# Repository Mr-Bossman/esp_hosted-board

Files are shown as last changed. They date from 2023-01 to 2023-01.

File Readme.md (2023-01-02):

# Test board for esp-hosted-ng

## Esp-hosted-ng is a SDIO/SPI WIFI/BT module for hosts runing Linux

To test ESP-Hosted-ng I designed this board to plug into and SD-card slot for easy testing.

The mothod I used before has some major signal integrity loss due to the jumper wires I used.

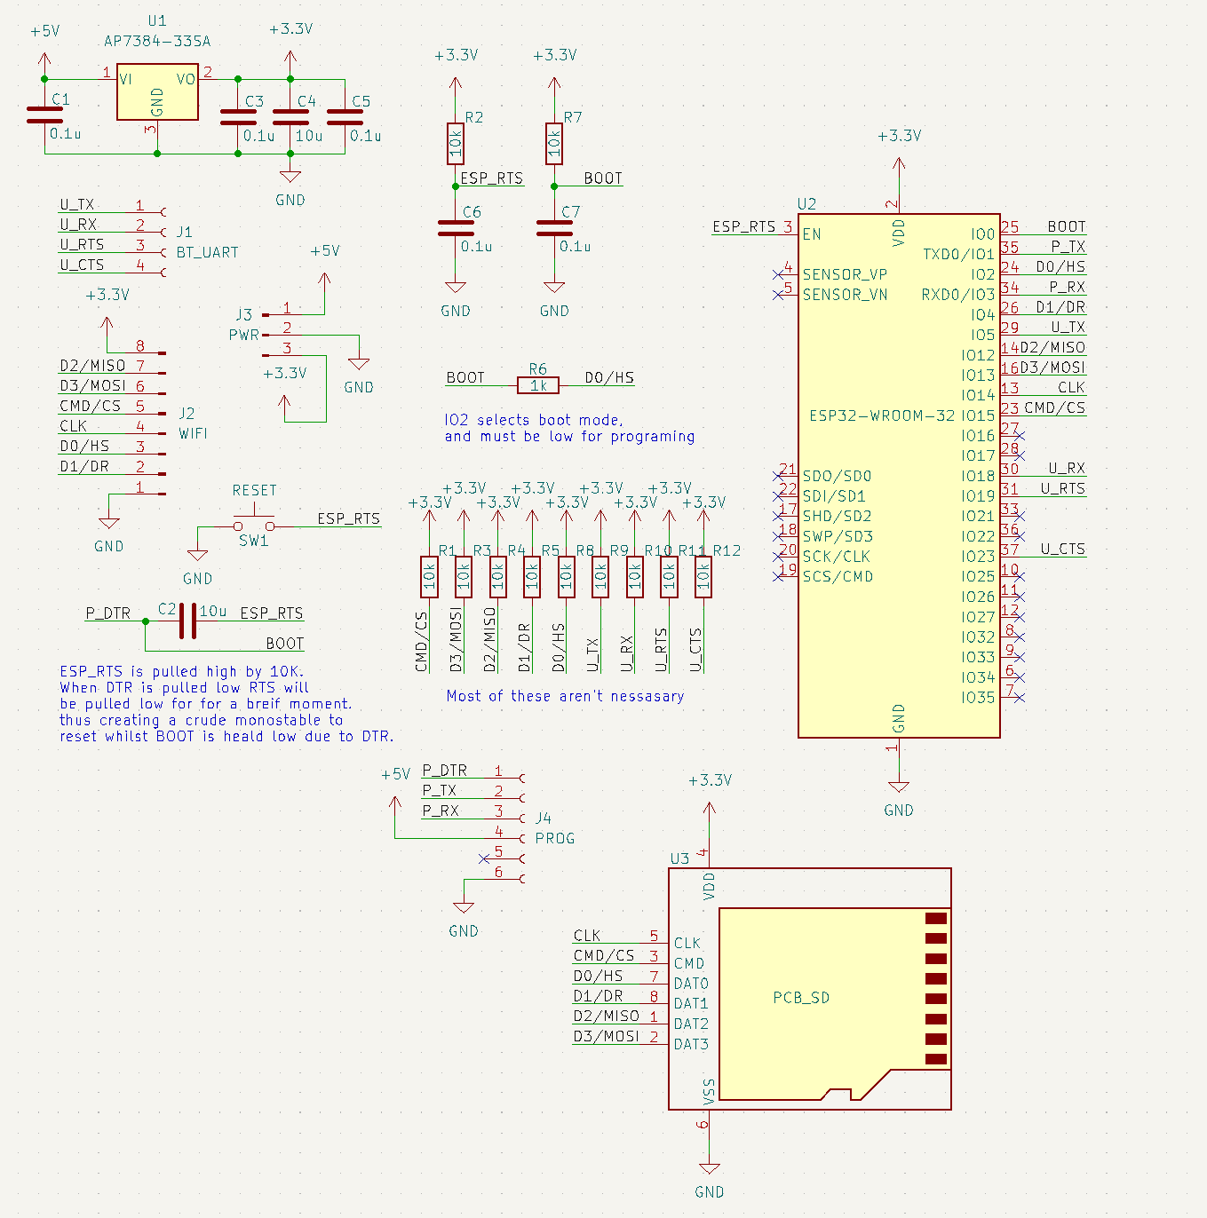
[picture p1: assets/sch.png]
Image of sch


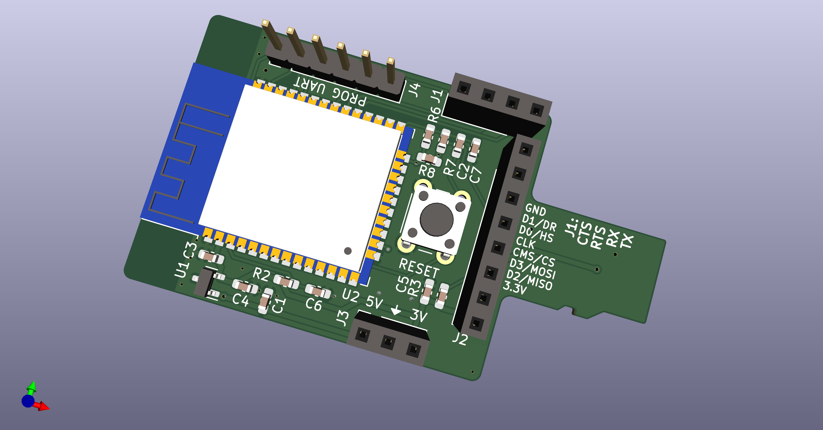
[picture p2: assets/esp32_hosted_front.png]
3D render of front


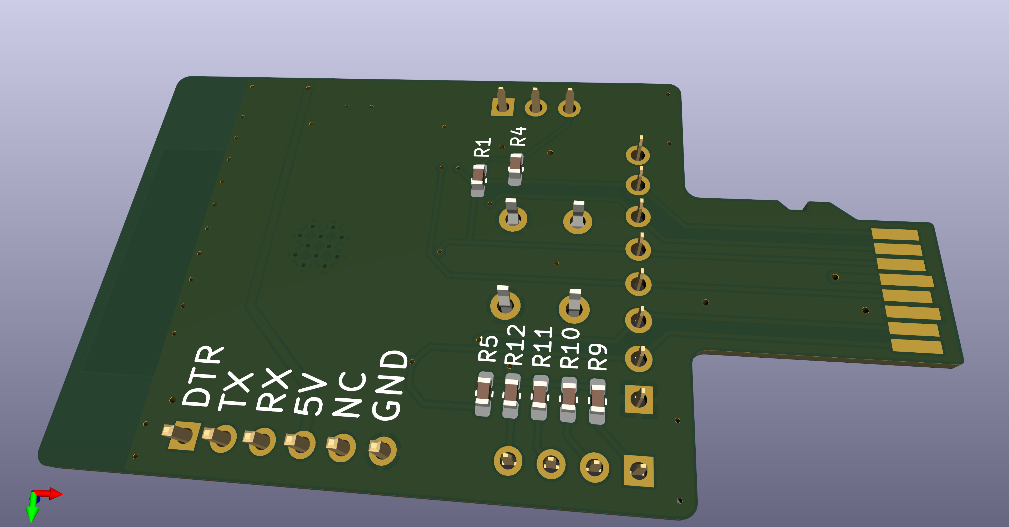
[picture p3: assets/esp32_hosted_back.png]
3D render of back


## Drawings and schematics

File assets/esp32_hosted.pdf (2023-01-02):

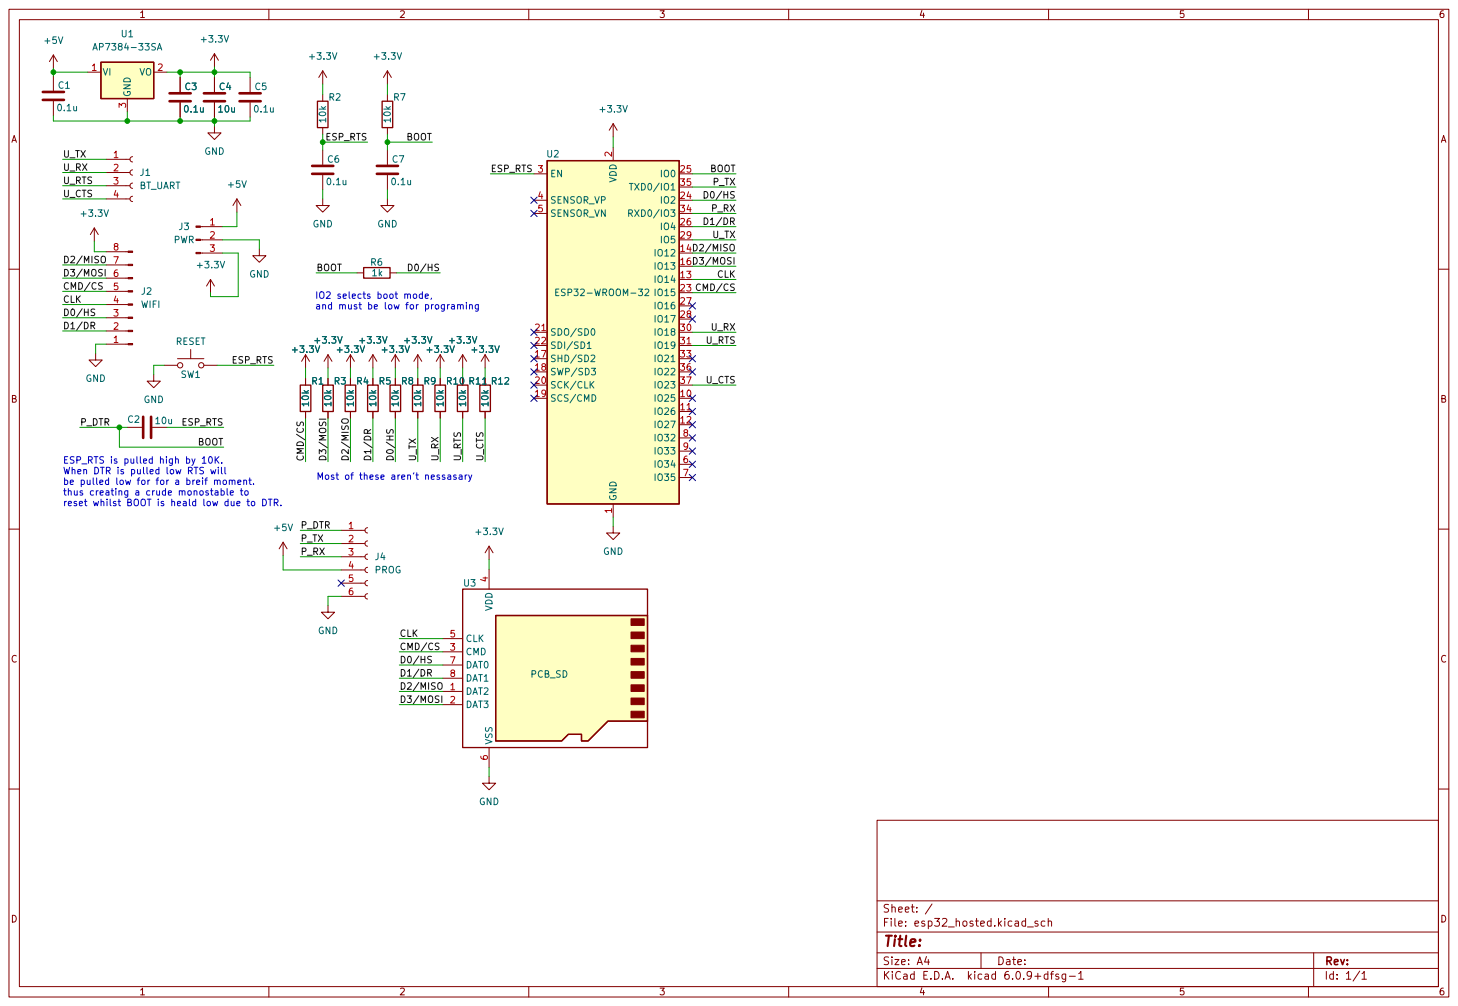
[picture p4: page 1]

reset whilst BOOT is heald low due to DTR. C3
J2WIFI GND 1234
BOOT U_CTS CLK D0/HS U_RX D2/MISO

IO2 selects boot mode, and must be low for programing

ESP_RTS is pulled high by 10K.
When DTR is pulled low RTS will
be pulled low for for a breif moment.
thus creating a crude monostable to

Most of these aren't nessasary

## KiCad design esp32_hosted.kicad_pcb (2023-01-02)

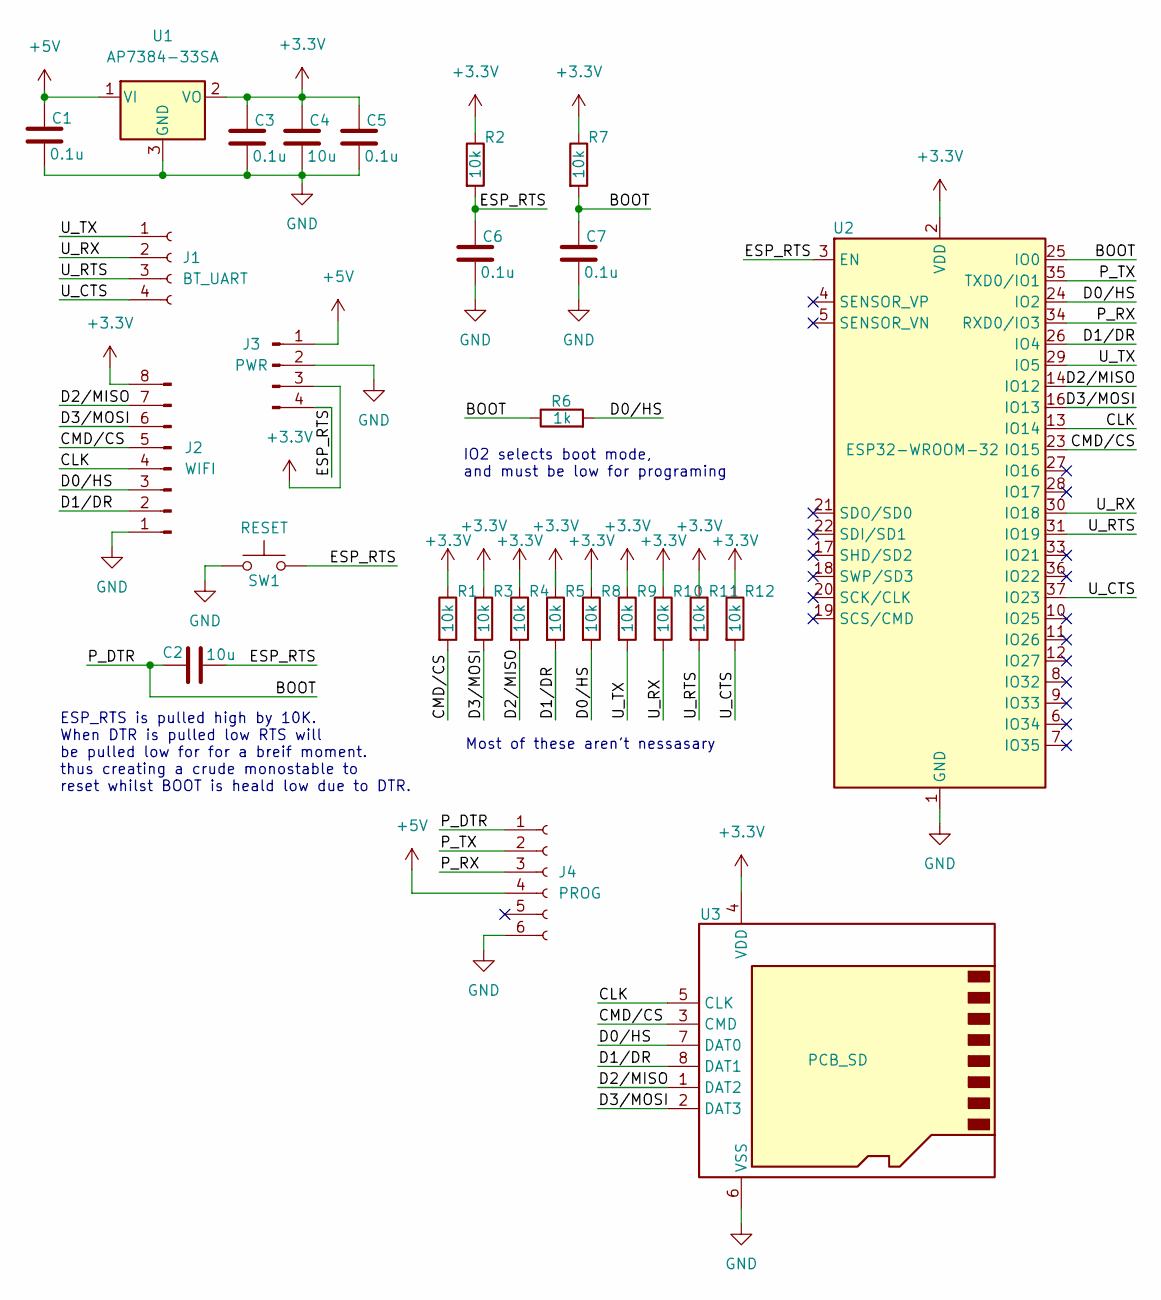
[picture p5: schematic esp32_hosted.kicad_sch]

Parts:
C1, C3, C5, C6, C7: 0.1u; C_0603_1608Metric_Pad1.08x0.95mm_HandSolder
C2, C4: 10u; C_0603_1608Metric_Pad1.08x0.95mm_HandSolder
J1: BT_UART; PinSocket_1x04_P2.54mm_Vertical
J2: WIFI; PinSocket_1x08_P2.54mm_Vertical
J3: PWR; PinSocket_1x04_P2.54mm_Vertical
J4: PROG; PinHeader_1x06_P2.54mm_Vertical
R1, R2, R3, R4, R5, R7, R8, R9, R10, R11, R12: 10k; C_0603_1608Metric_Pad1.08x0.95mm_HandSolder
R6: 1k; C_0603_1608Metric_Pad1.08x0.95mm_HandSolder
SW1: RESET; SW_PUSH_6mm
U1: AP7384-33SA; SOT-23
U2: ESP32-WROOM-32
U3: PCB_SD; PCB-SD

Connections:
+3.3V: C3.1, C4.1, C5.1, J2.8, J3.3, R1.1, R2.1, R3.1, R4.1, R5.1, R7.1, R8.1, R9.1, R10.1, R11.1, R12.1, U1.2 (VO), U2.2 (VDD), U3.4 (VDD)
+5V: C1.1, J3.1, J4.4, U1.1 (VI)
/BOOT: C2.1, C7.1, J4.1, R6.1, R7.2, U2.25 (IO0)
/CLK: J2.4, U2.13 (IO14), U3.5 (CLK)
/CMD/CS: J2.5, R1.2, U2.23 (IO15), U3.3 (CMD)
/D0/HS: J2.3, R6.2, R8.2, U2.24 (IO2), U3.7 (DAT0)
/D1/DR: J2.2, R5.2, U2.26 (IO4), U3.8 (DAT1)
/D2/MISO: J2.7, R4.2, U2.14 (IO12), U3.1 (DAT2)
/D3/MOSI: J2.6, R3.2, U2.16 (IO13), U3.2 (DAT3)
/ESP_RTS: C2.2, C6.1, J3.4, R2.2, SW1.2, U2.3 (EN)
/P_RX: J4.3, U2.34 (RXD0/IO3)
/P_TX: J4.2, U2.35 (TXD0/IO1)
/U_CTS: J1.4, R12.2, U2.37 (IO23)
/U_RTS: J1.3, R11.2, U2.31 (IO19)
/U_RX: J1.2, R10.2, U2.30 (IO18)
/U_TX: J1.1, R9.2, U2.29 (IO5)
GND: C1.2, C3.2, C4.2, C5.2, C6.2, C7.2, J2.1, J3.2, J4.6, SW1.1, U1.3 (GND), U2.1 (GND), U2.15 (GND), U2.38 (GND), U2.39 (GND), U3.6 (VSS)

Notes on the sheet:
IO2 selects boot mode, and must be low for programing
ESP_RTS is pulled high by 10K. When DTR is pulled low RTS will be pulled low for for a breif moment. thus creating a crude monostable to reset whilst BOOT is heald low due to DTR.
Most of these aren't nessasary

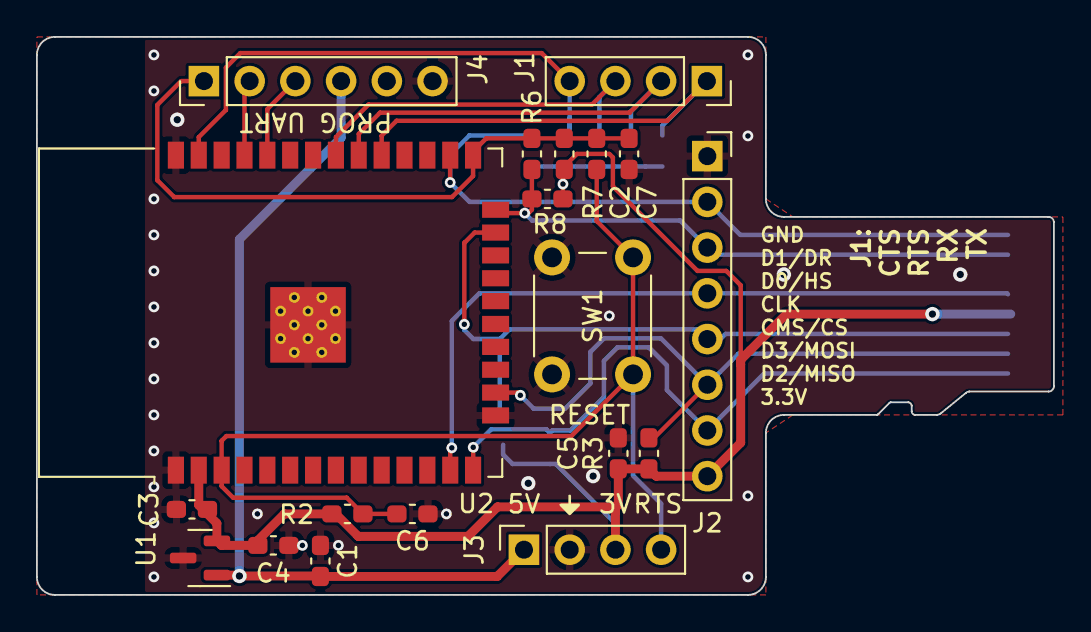
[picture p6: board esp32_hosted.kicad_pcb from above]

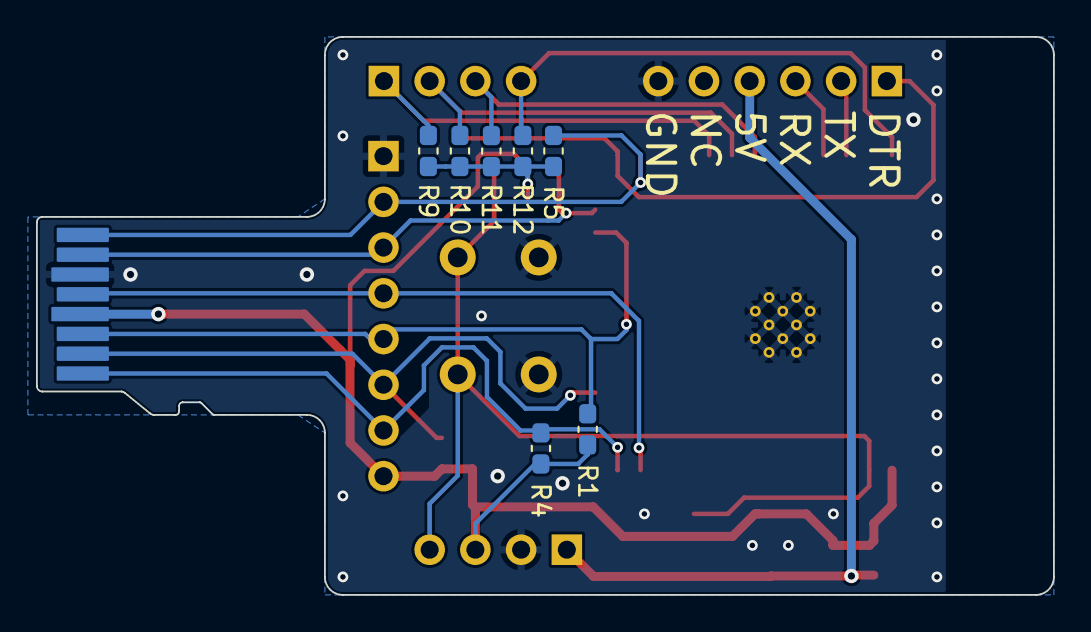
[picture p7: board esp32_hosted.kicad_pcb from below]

Board: 2 copper layers, 56.5 x 31.0 mm, 27 parts (7 on the bottom side), 17 nets.
